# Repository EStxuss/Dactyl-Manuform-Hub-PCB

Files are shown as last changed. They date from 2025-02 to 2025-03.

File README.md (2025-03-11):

Wired version has been tested. Wireless version has been ordered from fab and hasn't been tested

I'm not an electrical engineer. I'm open to suggestions for changes
# dactyl-mcu-pcb-mounts
PCBs that can fit with dactyl manuform cases generated with the PCB_MOUNT value for controller_mount_type thats available in kissetfall dactyl case generator fork: https://github.com/kissetfall/dactyl-keyboard

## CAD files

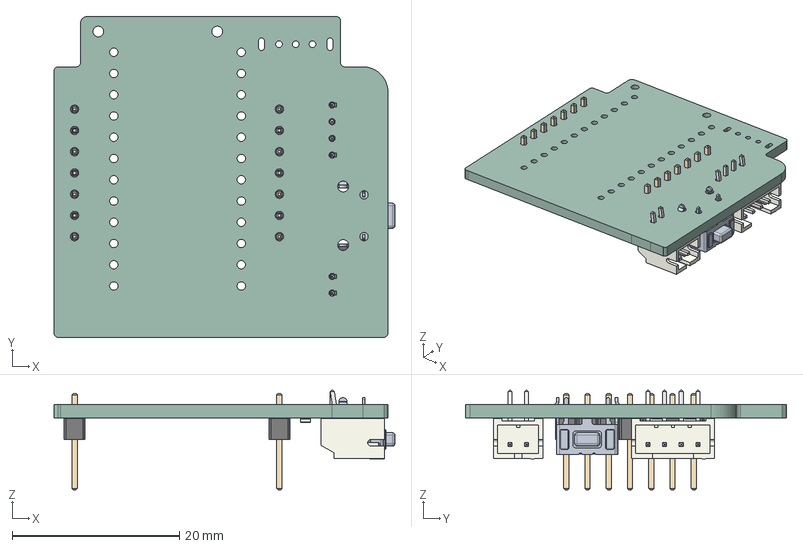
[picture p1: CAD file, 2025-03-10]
supermini_nrf52840_pcbholder_wireless_left/supermini_nrf52840_pcbholder_wireless_left.step
40.8 x 38.4 x 11.9 mm
JST_S2B_PH_K
R_0805_2012Metric x 2
PinHeader_1x07_P254mm_Vertical x 2
SKHLLC v3
JST_S4B_PH_K
supermini_nrf52840_pcbholder_wireless_right_PCB

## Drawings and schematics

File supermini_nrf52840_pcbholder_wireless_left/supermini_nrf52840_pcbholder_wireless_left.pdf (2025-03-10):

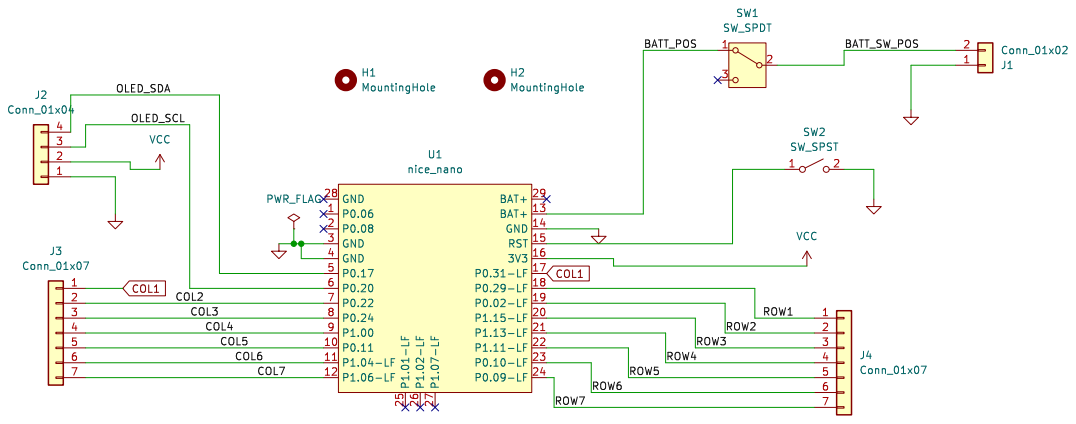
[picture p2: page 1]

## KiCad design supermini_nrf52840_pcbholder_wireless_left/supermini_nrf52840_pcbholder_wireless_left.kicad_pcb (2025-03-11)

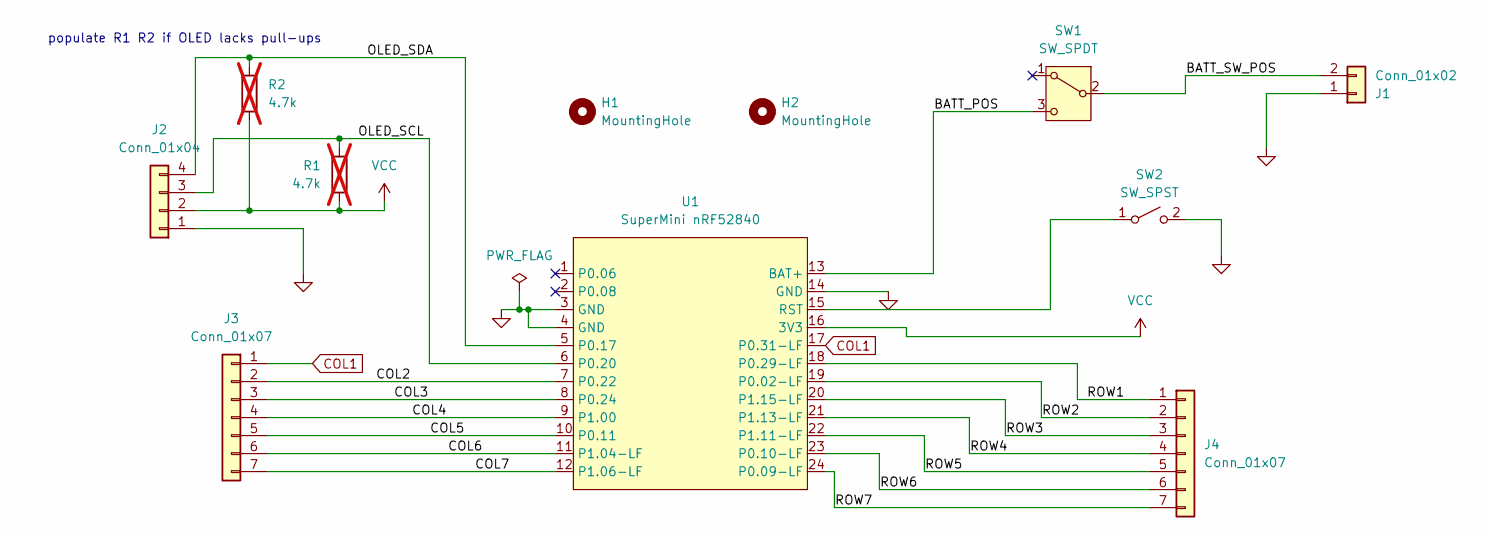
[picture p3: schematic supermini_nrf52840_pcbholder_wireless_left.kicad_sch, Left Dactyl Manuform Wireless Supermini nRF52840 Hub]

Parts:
H1, H2: MountingHole; M1.4_tapping_Hole_JLC
J1: Conn_01x02; JST_PH_S2B-PH-K_1x02_P2.00mm_Horizontal
J2: Conn_01x04; JST_PH_S4B-PH-K_1x04_P2.00mm_Horizontal
J3, J4: Conn_01x07; PinHeader_1x07_P2.54mm_Vertical
R1, R2: 4.7k; R_0805_2012Metric; not fitted
SW1: SW_SPDT; SW_SLW-864574-5A-RA-N-D
SW2: SW_SPST; SW_SKHLLCA010
U1: SuperMini nRF52840; SuperMini_nRF52840_H_USBup

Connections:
/BATT_POS: SW1.3 (C), U1.13 (BAT+)
/BATT_SW_POS: J1.2, SW1.2 (B)
/COL2: J3.2, U1.7 (P0.22)
/COL3: J3.3, U1.8 (P0.24)
/COL4: J3.4, U1.9 (P1.00)
/COL5: J3.5, U1.10 (P0.11)
/COL6: J3.6, U1.11 (P1.04-LF)
/COL7: J3.7, U1.12 (P1.06-LF)
/OLED_SCL: J2.3, R1.2, U1.6 (P0.20)
/OLED_SDA: J2.4, R2.2, U1.5 (P0.17)
/ROW1: J4.1, U1.18 (P0.29-LF)
/ROW2: J4.2, U1.19 (P0.02-LF)
/ROW3: J4.3, U1.20 (P1.15-LF)
/ROW4: J4.4, U1.21 (P1.13-LF)
/ROW5: J4.5, U1.22 (P1.11-LF)
/ROW6: J4.6, U1.23 (P0.10-LF)
/ROW7: J4.7, U1.24 (P0.09-LF)
COL1: J3.1, U1.17 (P0.31-LF)
GND: J1.1, J2.1, SW2.2 (B), U1.3 (GND), U1.4 (GND), U1.14 (GND)
unnamed: SW2.1 (A), U1.15 (RST)
VCC: J2.2, R1.1, R2.1, U1.16 (3V3)

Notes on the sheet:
populate R1 R2 if OLED lacks pull-ups

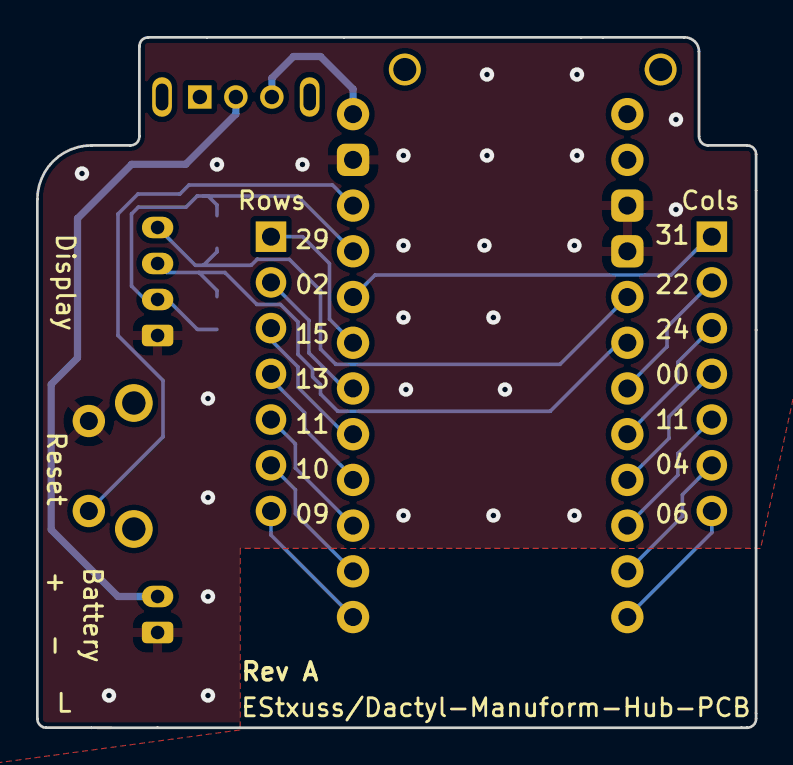
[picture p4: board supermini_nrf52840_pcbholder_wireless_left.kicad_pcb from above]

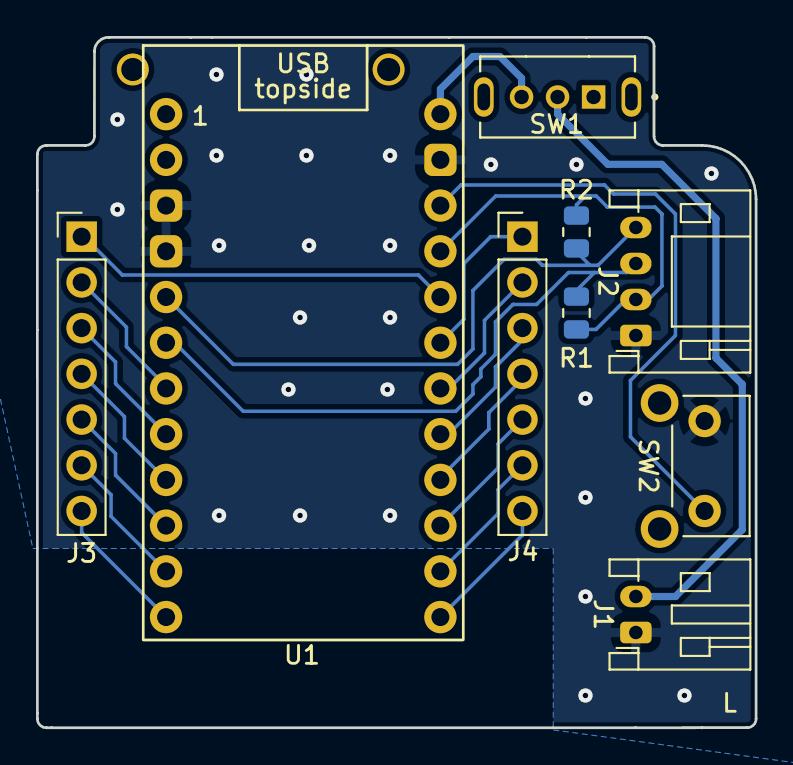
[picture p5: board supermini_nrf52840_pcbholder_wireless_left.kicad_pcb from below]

Board: 2 copper layers, 39.9 x 38.4 mm, 11 parts (9 on the bottom side), 21 nets.

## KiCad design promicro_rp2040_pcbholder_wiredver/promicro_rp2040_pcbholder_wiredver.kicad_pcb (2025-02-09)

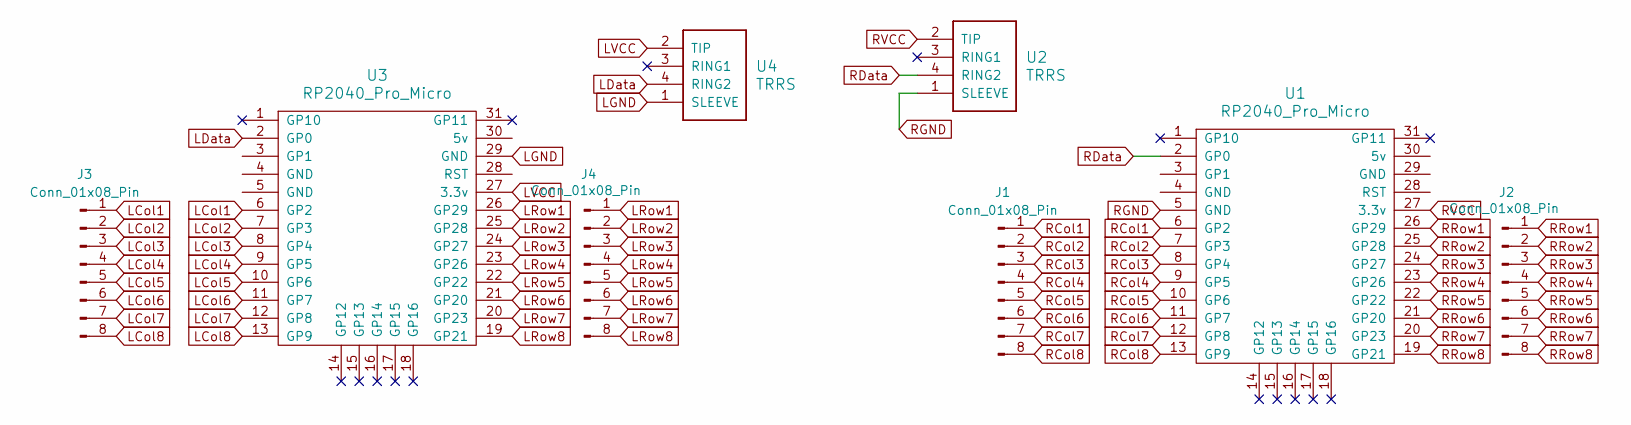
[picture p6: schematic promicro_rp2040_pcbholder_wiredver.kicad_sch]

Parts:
J1, J2, J3, J4: Conn_01x08_Pin; PinHeader_1x08_P2.54mm_Vertical_rev2
U1, U3: RP2040_Pro_Micro
U2, U4: TRRS; TRRS_PJ-320A

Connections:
LCol1: J3.1, U3.6 (GP2)
LCol2: J3.2, U3.7 (GP3)
LCol3: J3.3, U3.8 (GP4)
LCol4: J3.4, U3.9 (GP5)
LCol5: J3.5, U3.10 (GP6)
LCol6: J3.6, U3.11 (GP7)
LCol7: J3.7, U3.12 (GP8)
LCol8: J3.8, U3.13 (GP9)
LData: U3.2 (GP0), U4.4 (RING2)
LGND: U3.29 (GND), U4.1 (SLEEVE)
LRow1: J4.1, U3.26 (GP29)
LRow2: J4.2, U3.25 (GP28)
LRow3: J4.3, U3.24 (GP27)
LRow4: J4.4, U3.23 (GP26)
LRow5: J4.5, U3.22 (GP22)
LRow6: J4.6, U3.21 (GP20)
LRow7: J4.7, U3.20 (GP23)
LRow8: J4.8, U3.19 (GP21)
LVCC: U3.27 (3.3v), U4.2 (TIP)
RCol1: J1.1, U1.6 (GP2)
RCol2: J1.2, U1.7 (GP3)
RCol3: J1.3, U1.8 (GP4)
RCol4: J1.4, U1.9 (GP5)
RCol5: J1.5, U1.10 (GP6)
RCol6: J1.6, U1.11 (GP7)
RCol7: J1.7, U1.12 (GP8)
RCol8: J1.8, U1.13 (GP9)
RData: U1.2 (GP0), U2.4 (RING2)
RGND: U1.5 (GND), U2.1 (SLEEVE)
RRow1: J2.1, U1.26 (GP29)
RRow2: J2.2, U1.25 (GP28)
RRow3: J2.3, U1.24 (GP27)
RRow4: J2.4, U1.23 (GP26)
RRow5: J2.5, U1.22 (GP22)
RRow6: J2.6, U1.21 (GP20)
RRow7: J2.7, U1.20 (GP23)
RRow8: J2.8, U1.19 (GP21)
RVCC: U1.27 (3.3v), U2.2 (TIP)

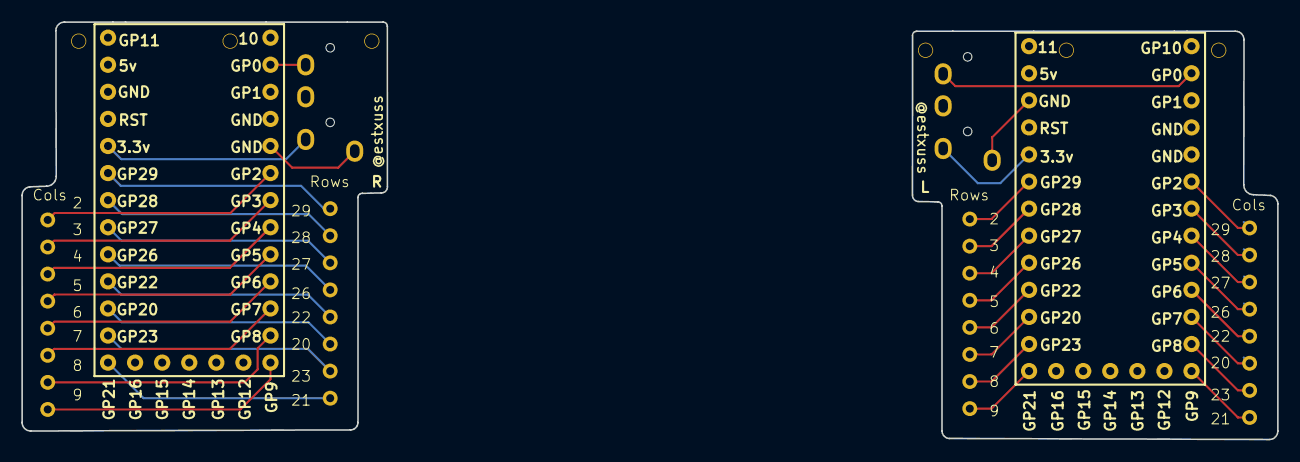
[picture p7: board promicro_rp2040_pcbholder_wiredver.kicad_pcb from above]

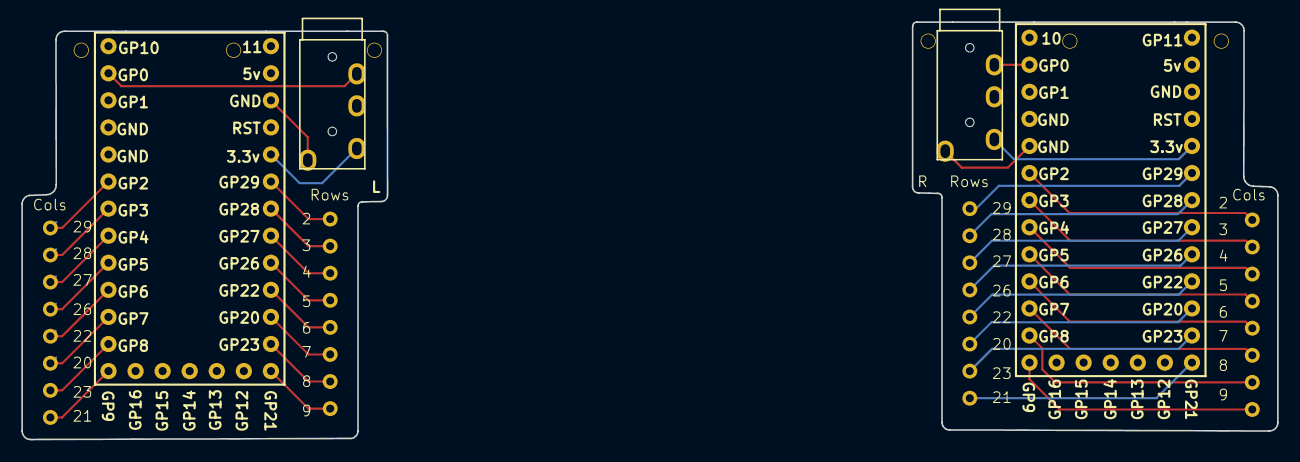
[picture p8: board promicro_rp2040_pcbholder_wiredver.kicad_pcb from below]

Board: 2 copper layers, 117.8 x 39.2 mm, 8 parts (8 on the bottom side), 38 nets.

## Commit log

2025-01-01 rp2040 promicro holder partial completion
    [promicro-type-C_holder.kicad_pcb, promicro_rp2040_pcbholder_wiredver.kicad_pcb, promicro_rp2040_pcbholder_wiredver.kicad_sch]
2025-01-01 schematic naming
    [promicro-type-C_holder.kicad_pcb, promicro_rp2040_pcbholder_wiredver.kicad_pcb, promicro_rp2040_pcbholder_wiredver.kicad_sch]
2025-01-02 initial design done. Ordered for testing
    [promicro_rp2040_pcbholder_leftside.kicad_pcb, promicro_rp2040_pcbholder_rightside.kicad_pcb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]
2025-01-20 tested working. Swap left side pcb's rows and cols wire holes
    [promicro_rp2040_pcbholder_leftside.kicad_pcb, promicro_rp2040_pcbholder_wiredver.kicad_pcb]
2025-02-09 slight change m1.4 right side pcb hole spacing
    [promicro_rp2040_pcbholder_leftside.kicad_pcb, promicro_rp2040_pcbholder_rightside.kicad_pcb, promicro_rp2040_pcbholder_wiredver.kicad_pcb]
2025-02-25 add supermini nrf52840 pcb holder for zmk wireless dactyls
    [supermini_nrf52840_pcbholder_wireless.kicad_pcb, supermini_nrf52840_pcbholder_wireless.kicad_sch]
2025-03-03 change power switch footprint and supermini board placement
    [supermini_nrf52840_pcbholder_wireless.kicad_pcb, supermini_nrf52840_pcbholder_wireless.kicad_sch]
2025-03-08 mostly done supermini wireless hub version
    [supermini_nrf52840_pcbholder_wireless_left.kicad_pcb, supermini_nrf52840_pcbholder_wireless_left.kicad_sch]
2025-03-10 add optional i2c pull ups
    [supermini_nrf52840_pcbholder_wireless_right.kicad_pcb, supermini_nrf52840_pcbholder_wireless_right.kicad_sch, supermini_nrf52840_pcbholder_wireless_right.step]
2025-03-10 edge cuts change
    [supermini_nrf52840_pcbholder_wireless_right.kicad_pcb, supermini_nrf52840_pcbholder_wireless_right.step]
2025-03-11 create left side and tweaks
    [supermini_nrf52840_pcbholder_wireless_left.kicad_pcb, supermini_nrf52840_pcbholder_wireless_left.kicad_sch, supermini_nrf52840_pcbholder_wireless_left.step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]
2025-03-11 remove unused pins from supermini symbol
    [supermini_nrf52840_pcbholder_wireless.kicad_pcb, supermini_nrf52840_pcbholder_wireless.kicad_sch, supermini_nrf52840_pcbholder_wireless_left.kicad_pcb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]
